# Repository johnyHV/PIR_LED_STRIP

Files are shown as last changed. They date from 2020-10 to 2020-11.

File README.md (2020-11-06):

# PIR_LED_STRIP

Control board with PIR senzor, IR remote control and LED strip. LED strip contain addressable SK6812 RGBW LEDs. It is a board for corridor lighting when motion is detected

Animation

Image description

Color presentation
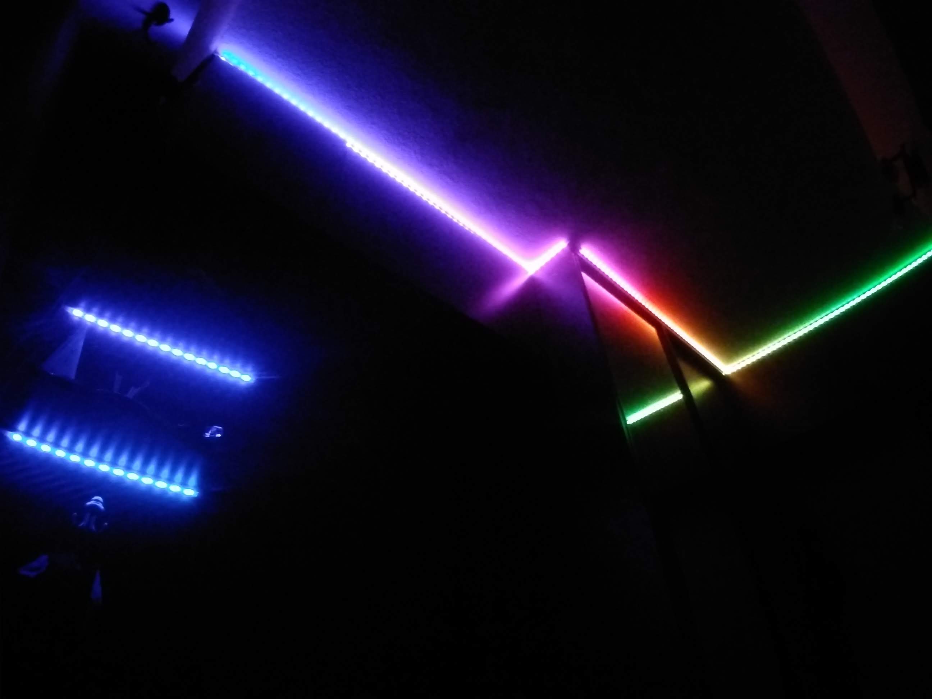
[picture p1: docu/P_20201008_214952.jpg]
Image description


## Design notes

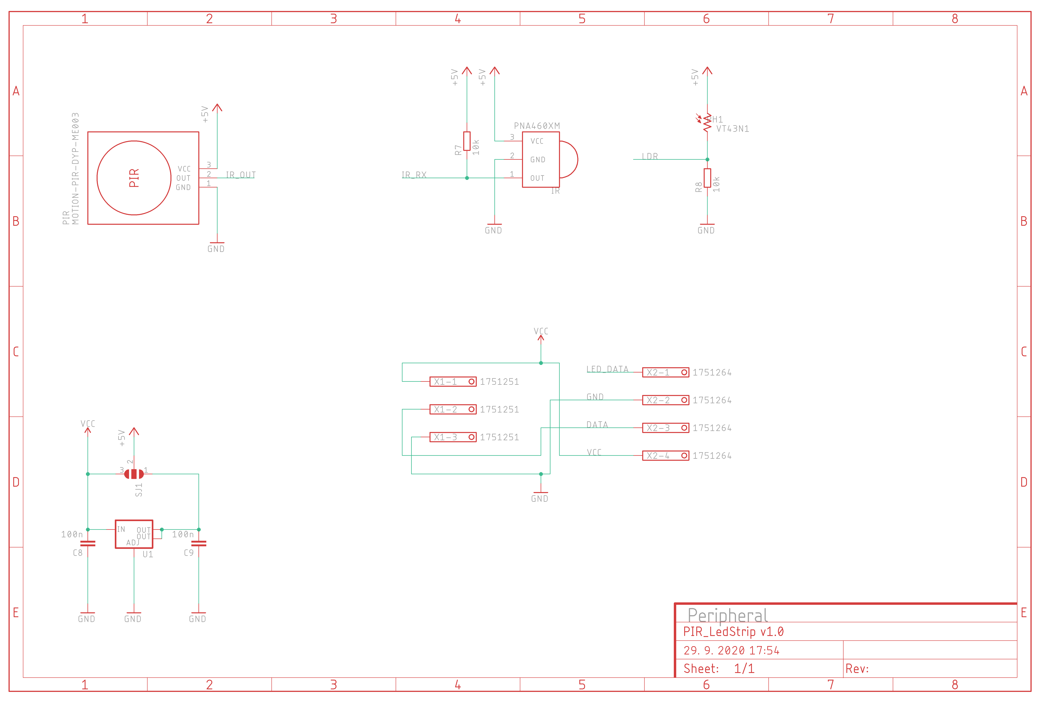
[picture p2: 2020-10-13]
docu/schematic_peripheral.png

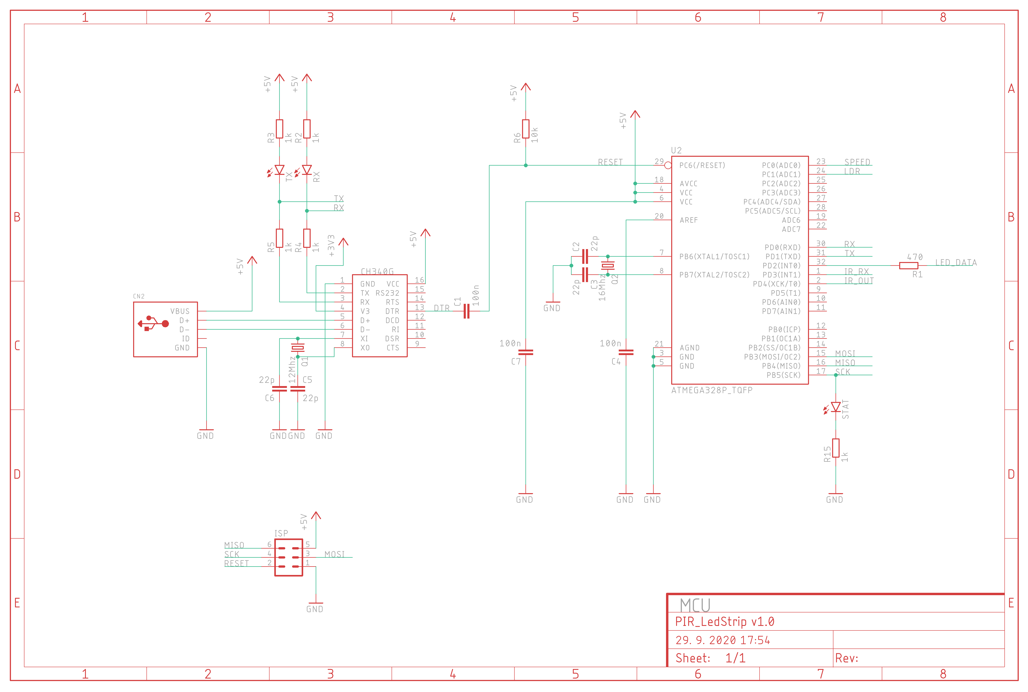
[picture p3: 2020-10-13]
docu/schematic_MCU.png

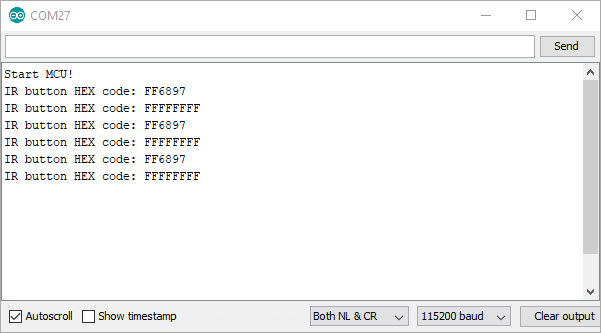
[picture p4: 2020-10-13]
docu/monitor.png

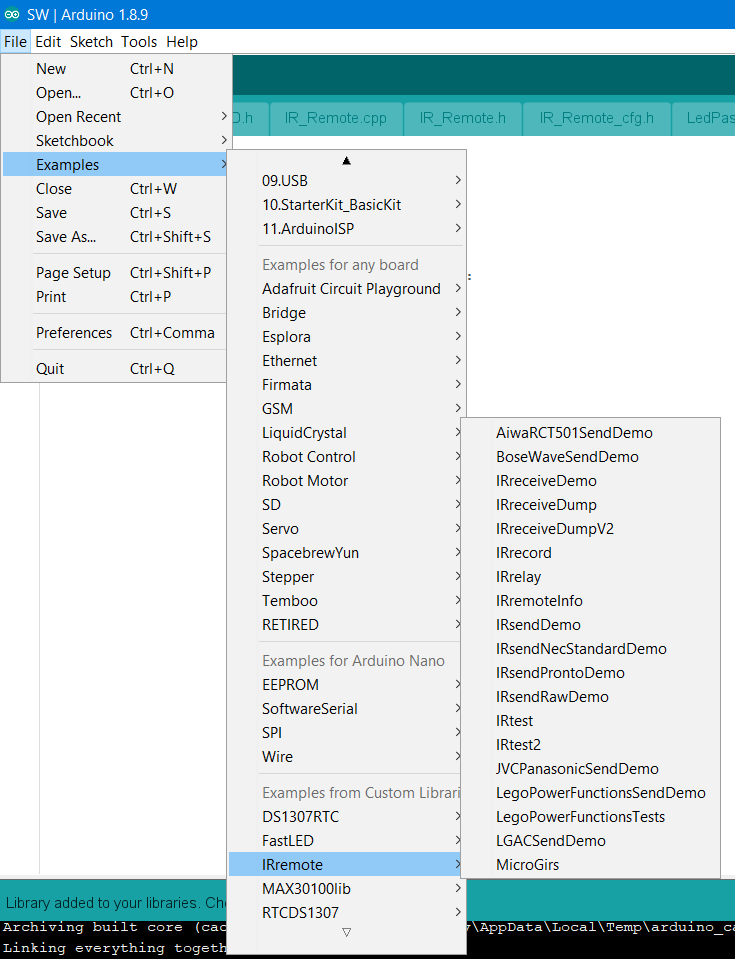
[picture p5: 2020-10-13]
docu/add_lib_4.png

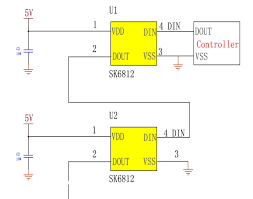
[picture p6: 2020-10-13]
docu/connect LED.png

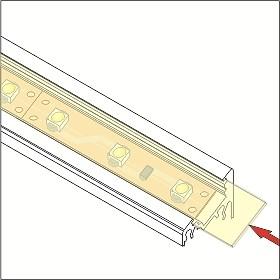
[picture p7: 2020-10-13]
docu/konstrukcia/CORNER10/hlinikovy-profil-pre-led-pasy-corner (2).jpg

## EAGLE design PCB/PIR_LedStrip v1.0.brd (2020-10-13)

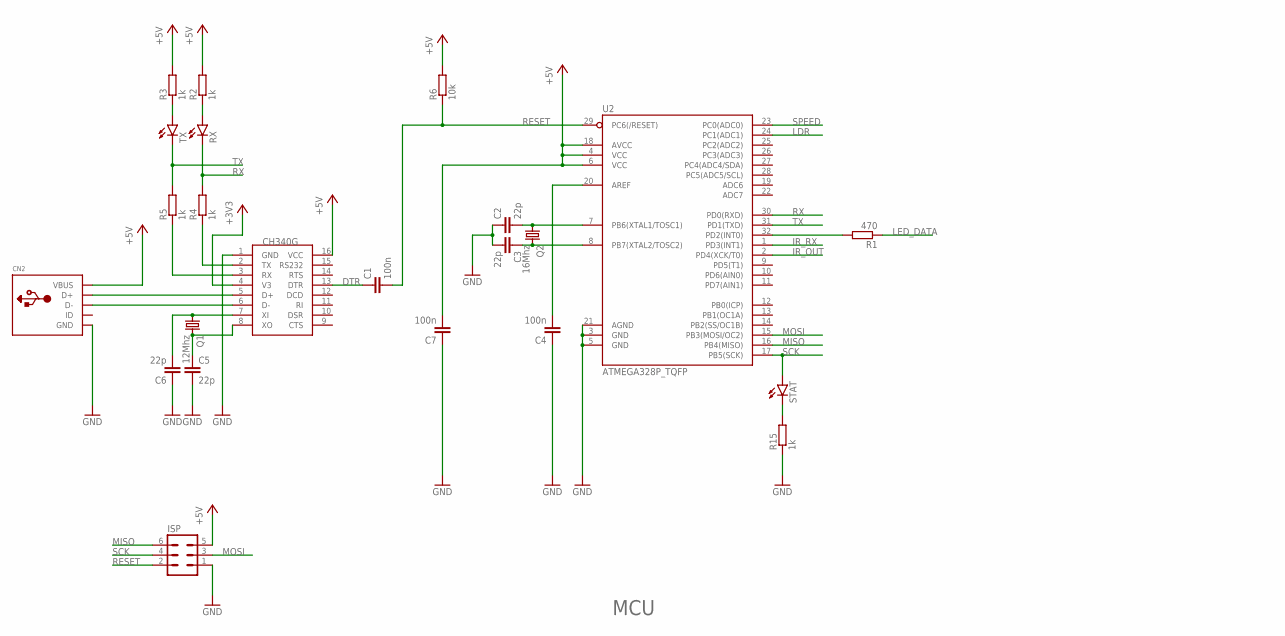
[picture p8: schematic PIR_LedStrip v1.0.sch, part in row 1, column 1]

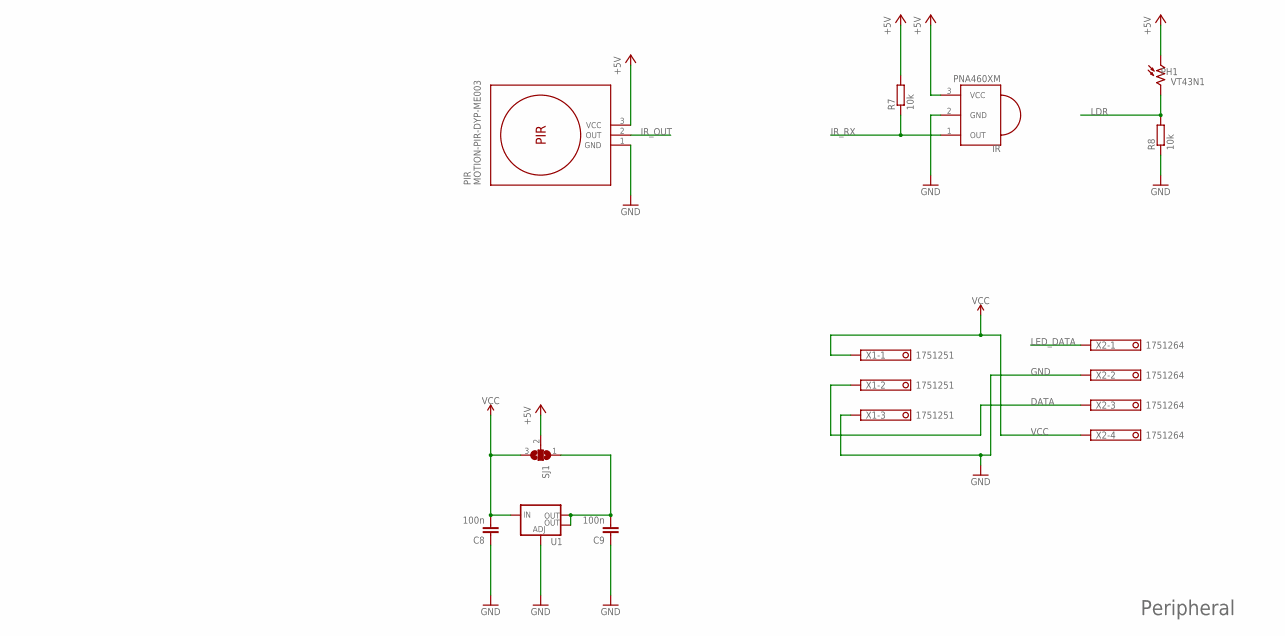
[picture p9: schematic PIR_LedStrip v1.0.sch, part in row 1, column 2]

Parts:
C1, C4, C7, C8, C9: 100n; C0603
C2, C3, C5, C6: 22p; C0603
CN2: USBMINIB; USB-MINIB
IR: PNA460XM
ISP: MA03-2
PH1: VT43N1; VT400
PIR: MOTION-PIR-DYP-ME003
Q1: 12Mhz; HC49UP
Q2: 16Mhz; HC49UP
R1: 470; R0603
R2, R3, R4, R5, R15: 1k; R0603
R6, R7, R8: 10k; R0603
RX: LEDSML0805; SML0805
SJ1: SJ2W; SJ_2
STAT: LEDSML0805; SML0805
TX: LEDSML0805; SML0805
U1: V_REG_LM1117SOT223; SOT223
U2: ATMEGA328P_TQFP; TQFP32-08
U$1: CH340G; SOIC16
X1: 1751251
X2: 1751264

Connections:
+3V3: U$1.4 (V3)
+5V: C7.2, CN2.VBUS, IR.3 (VCC), ISP.5, PH1.1, PIR.3 (VCC), R2.2, R3.2, R6.2, R7.2, SJ1.2, U2.4 (VCC), U2.6 (VCC), U2.18 (AVCC), U$1.16 (VCC)
DATA: X1.2, X2.3
DTR: C1.1, U$1.13 (DTR)
GND: C2.1, C3.2, C4.1, C5.2, C6.1, C7.1, C8.1, C9.1, CN2.GND, IR.2 (GND), ISP.1, PIR.1 (GND), R8.1, R15.1, U1.1 (ADJ), U2.3 (GND), U2.5 (GND), U2.21 (AGND), U$1.1 (GND), X1.3, X2.2
IR_OUT: PIR.2 (OUT), U2.2 (PD4(XCK/T0))
IR_RX: IR.1 (OUT), R7.1, U2.1 (PD3(INT1))
LDR: PH1.2, R8.2, U2.24 (PC1(ADC1))
LED_DATA: R1.1, X2.1
MISO: ISP.6, U2.16 (PB4(MISO))
MOSI: ISP.3, U2.15 (PB3(MOSI/OC2))
unnamed: CN2.D+, U$1.5 (D+)
unnamed: R1.2, U2.32 (PD2(INT0))
unnamed: CN2.D-, U$1.6 (D-)
unnamed: R5.1, U$1.3 (RX)
unnamed: R4.1, U$1.2 (TX)
unnamed: C2.2, Q2.1, U2.7 (PB6(XTAL1/TOSC1))
unnamed: C6.2, Q1.1, U$1.7 (XI)
unnamed: C5.1, Q1.2, U$1.8 (XO)
unnamed: R2.1, RX.A
unnamed: R3.1, TX.A
unnamed: C3.1, Q2.2, U2.8 (PB7(XTAL2/TOSC2))
unnamed: C4.2, U2.20 (AREF)
unnamed: C9.2, SJ1.1, U1.2 (OUT), U1.4 (OUT)
unnamed: R15.2, STAT.C
RESET: C1.2, ISP.2, R6.1, U2.29 (PC6(/RESET))
RX: R4.2, RX.C, U2.30 (PD0(RXD))
SCK: ISP.4, STAT.A, U2.17 (PB5(SCK))
SPEED: U2.23 (PC0(ADC0))
TX: R5.2, TX.C, U2.31 (PD1(TXD))
VCC: C8.2, SJ1.3, U1.3 (IN), X1.1, X2.4

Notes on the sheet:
MCU
Peripheral

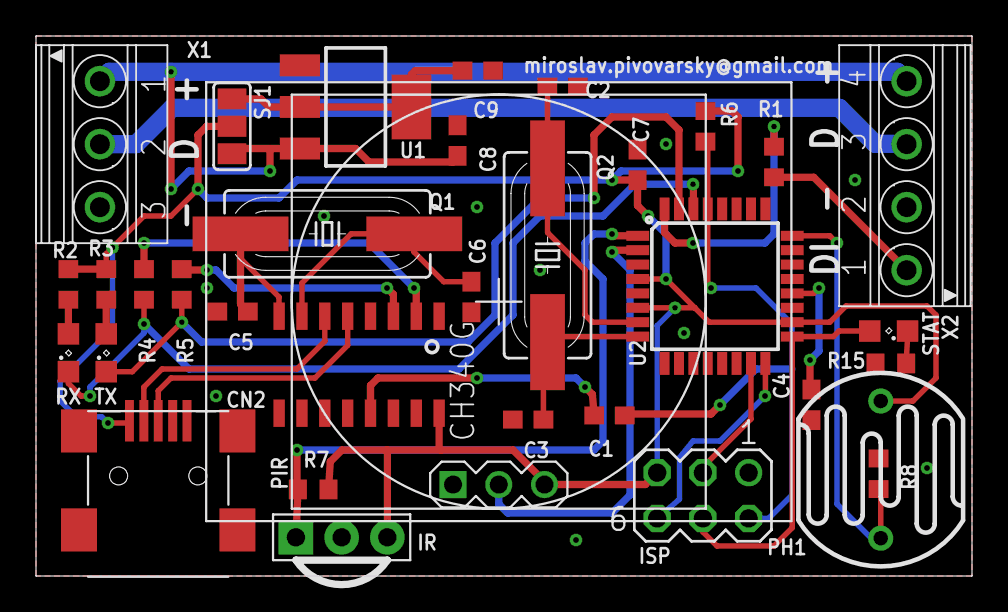
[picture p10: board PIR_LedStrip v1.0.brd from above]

Board: 2 copper layers, 52.0 x 30.0 mm, 34 parts (0 on the bottom side), 29 nets.

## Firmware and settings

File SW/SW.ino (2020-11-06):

#include "Config.h"
#include "IR_Remote.h"
#include "LedPas.h"
#include "Premenne.h"
#include "PIR_Sensor.h"
#include "TimerOne.h"

void timerIsr();

void setup() {
  /* Init serioveho rozhrania */  
  Serial.begin(115200);
  /* Init PIR senzora */
  PIR_Init();
  EnablePir = true;
  /* Init IR prijimaca */
#if (IR_REMOTE_ENABLE == true)
  IR_rx.enableIRIn();
#endif

  /* init LED pasu */
  LED_StripClear();
  /* Init STATUS LED */
  pinMode(STATUS_LED, OUTPUT);
  digitalWrite(STATUS_LED, LOW);

  /* Init casovaca */
  Timer1.initialize(1000000);       ///< Nastavenie casovaca na dlzku 100000 microseconds
  Timer1.attachInterrupt(timerIsr); ///< attach funkcie pre prerusenie 

  Serial.println(F("Start MCU!"));
}

void loop() {
  /* kontrola IR prijimaca */
  IR_Scan();

  /* kontrola detekcie pohybu z PIR senzora, a kontrola zapnuta detekcie pohybu cez IR dialkove ovladanie */
  if ((PIR_CheckStatus() == true) && (EnablePir == true)) {
    Serial.println(F("Motion detection! "));
    TimerCounter = 0;
    StartStripOn = true;
  }

  /* kontrola zapnutia LED pasu */
  if ((StartStripOn == true) && (LedStripStatus == false)) {
    Serial.println(F("Strip ON"));
    LED_StripOn();
    LED_ShelfOneOn();
    LED_ShelfTwoOn();
    LedStripStatus = true;
    StartStripOn = false;
  }

  /* kontrola vyprsania timeoutu, a vypnutie LED pasu */
  if ((TimerCounter >= LED_STRIP_TIMEOUT) && (LedStripStatus == true)) {
    Serial.println(F("Strip OFF"));
    LED_ShelfTwoOff();
    LED_ShelfOneOff();
    LED_StripOff();
    LedStripStatus = false;
    StartStripOn = false;
  }
}

/// --------------------------
/// Custom ISR Timer Routine
/// --------------------------
void timerIsr() {
  TimerCounter++;
  Serial.print(F("ISR: "));
  Serial.println(TimerCounter);
}

/* EOF */

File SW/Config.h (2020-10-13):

/**
 * @file Config.h
 *
 * @brief konfiguracia MCU
 *
 * @author Miroslav Pivovarsky
 * Contact: miroslav.pivovarsky@gmail.com
 * 
 * @bug: no know bug
 *
 */

#ifndef _COFIG_H_
#define _COFIG_H_

#define LED_PIN             2       ///< Pin for LED strip
#define PIR_IN              4       ///< Pin for PIR sensor
#define IR_REC_INPUT        3       ///< Pin for IR receiver
#define LDR                 A1      ///< Pin for photo resistor
#define STATUS_LED          13      ///< Pin for STATUS led

#endif

/* EOF */

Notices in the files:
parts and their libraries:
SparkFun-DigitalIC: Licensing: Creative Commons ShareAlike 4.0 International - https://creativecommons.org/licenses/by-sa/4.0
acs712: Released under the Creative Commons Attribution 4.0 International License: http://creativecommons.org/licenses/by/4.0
